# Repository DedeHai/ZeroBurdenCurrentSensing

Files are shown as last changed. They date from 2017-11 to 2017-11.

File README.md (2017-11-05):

# ZeroBurdenCurrentSensing
A circuit I made to measure the dynamically changing currents in low power microcontroller applications.

a detailed description is avialable on my blog: https://bashtelorofscience.wordpress.com/2017/11/05/zero-burden-voltage-current-amplifier/

Finished Circuit 
Example measurement

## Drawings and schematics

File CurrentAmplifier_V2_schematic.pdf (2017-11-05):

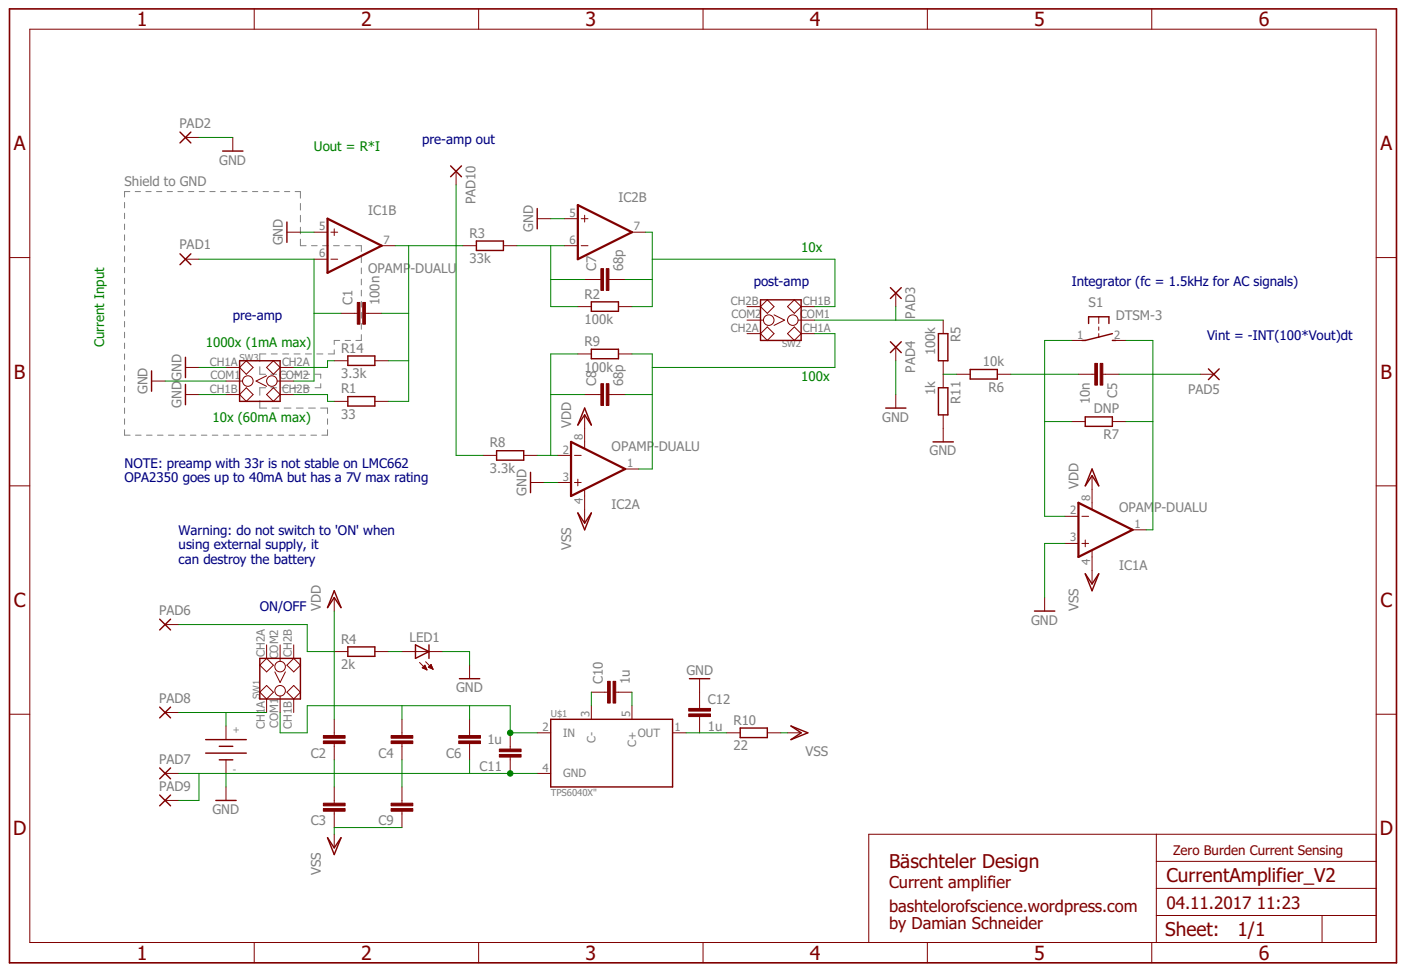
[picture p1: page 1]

pre-amp out Uout = R*I

Integrator (fc = 1.5kHz for AC signals)

Vint = -INT(100*Vout)dt

NOTE: preamp with 33r is not stable on LMC662
OPA2350 goes up to 40mA but has a 7V max rating

Warning: do not switch to 'ON' when
using external supply, it
can destroy the battery

Zero Burden Current Sensing Bäschteler Design

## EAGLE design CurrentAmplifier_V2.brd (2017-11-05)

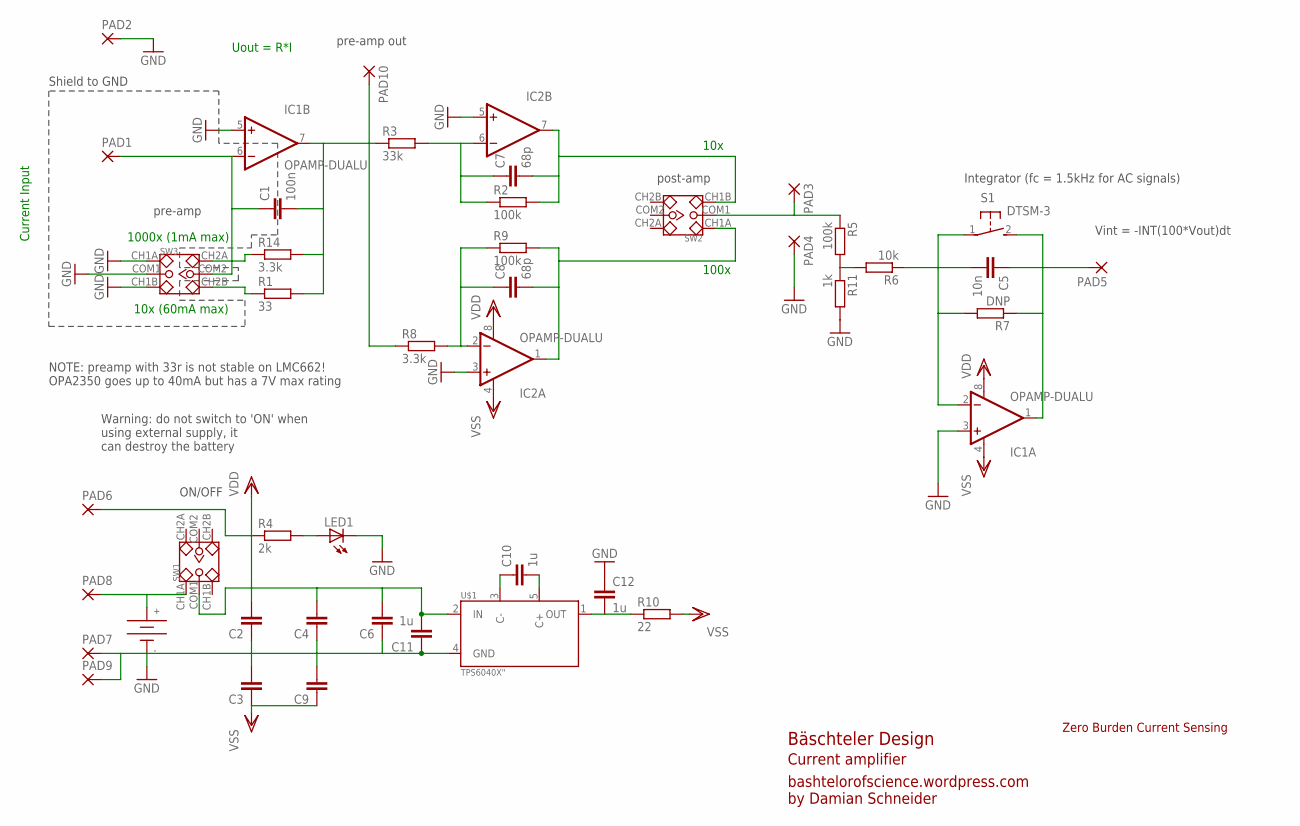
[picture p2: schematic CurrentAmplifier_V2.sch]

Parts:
C1: 100n; C0805K
C2, C3, C4: C-EUC0805; C0805
C5: 10n; C0805K
C6, C9: C-EUC1206; C1206
C7, C8: 68p; C0603
C10, C11, C12: 1u; C0603
CR1: DX_CR2032HANDSOLDER; DX_CR2032_SMD_HANDSOLDER
IC1, IC2: OPAMP-DUALU; SO08
LED1: LEDCHIP-LED0805; CHIP-LED0805
PAD1, PAD2, PAD3, PAD4, PAD5, PAD6, PAD7, PAD8, PAD9, PAD10: 1,6/0,9
R1: 33; R0805
R2, R5, R9: 100k; R0603
R3: 33k; R0603
R4: 2k; R0603
R6: 10k; R0603
R7: DNP; R0805
R8: 3.3k; R0603
R10: 22; R0805
R11: 1k; R0603
R14: 3.3k; R0805
S1: DTSM-3
SW1, SW2, SW3: DIP-TOGGLE-SWITCH-2CH-(2X3P-2.54); SW6-2.54-9.0X3.5X3.2+2.0MM
U$1: TPS6040X"; SOT23-5

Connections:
+: CR1.P$1 (+), PAD8.1, SW1.CH1A
GND: C2.1, C3.2, C4.1, C6.1, C9.2, C11.1, C12.1, CR1.P$2 (-), IC1.3 (+IN), IC1.5 (+IN), IC2.3 (+IN), IC2.5 (+IN), LED1.C, PAD2.1, PAD4.1, PAD7.1, PAD9.1, R11.2, SW3.CH1A, SW3.CH1B, SW3.COM1, U$1.4 (GND)
unnamed: C1.2, IC1.7 (OUT), PAD10.1, R1.2, R3.1, R8.1, R14.2
unnamed: C7.1, IC2.6 (-IN), R2.1, R3.2
unnamed: R5.2, R6.2, R11.1
unnamed: C7.2, IC2.7 (OUT), R2.2, SW2.CH1B
unnamed: R14.1, SW3.CH2A
unnamed: C10.1, U$1.3 (C-)
unnamed: C10.2, U$1.5 (C+)
unnamed: LED1.A, R4.2
unnamed: C5.2, IC1.2 (-IN), R6.1, R7.2, S1.1
unnamed: C5.1, IC1.1 (OUT), PAD5.1, R7.1, S1.2
unnamed: C8.1, IC2.2 (-IN), R8.2, R9.1
unnamed: C8.2, IC2.1 (OUT), R9.2, SW2.CH1A
unnamed: PAD3.1, R5.1, SW2.COM1
unnamed: C12.2, R10.1, U$1.1 (OUT)
unnamed: C1.1, IC1.6 (-IN), PAD1.1, SW3.COM2
unnamed: R1.1, SW3.CH2B
VDD: C2.2, C4.2, C6.2, C11.2, IC1.8 (V+), IC2.8 (V+), PAD6.1, R4.1, SW1.COM1, U$1.2 (IN)
VSS: C3.1, C9.1, IC1.4 (V-), IC2.4 (V-), R10.2

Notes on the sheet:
Uout = R*I
Current Input
Shield to GND
10x
100x
ON/OFF
post-amp
1000x (1mA max)
10x (60mA max)
pre-amp
Zero Burden Current Sensing
Integrator (fc = 1.5kHz for AC signals)
Warning: do not switch to 'ON' when using external supply, it can destroy the battery
Vint = -INT(100*Vout)dt
NOTE: preamp with 33r is not stable on LMC662! OPA2350 goes up to 40mA but has a 7V max rating
pre-amp out
Bäschteler Design
bashtelorofscience.wordpress.com by Damian Schneider
Current amplifier

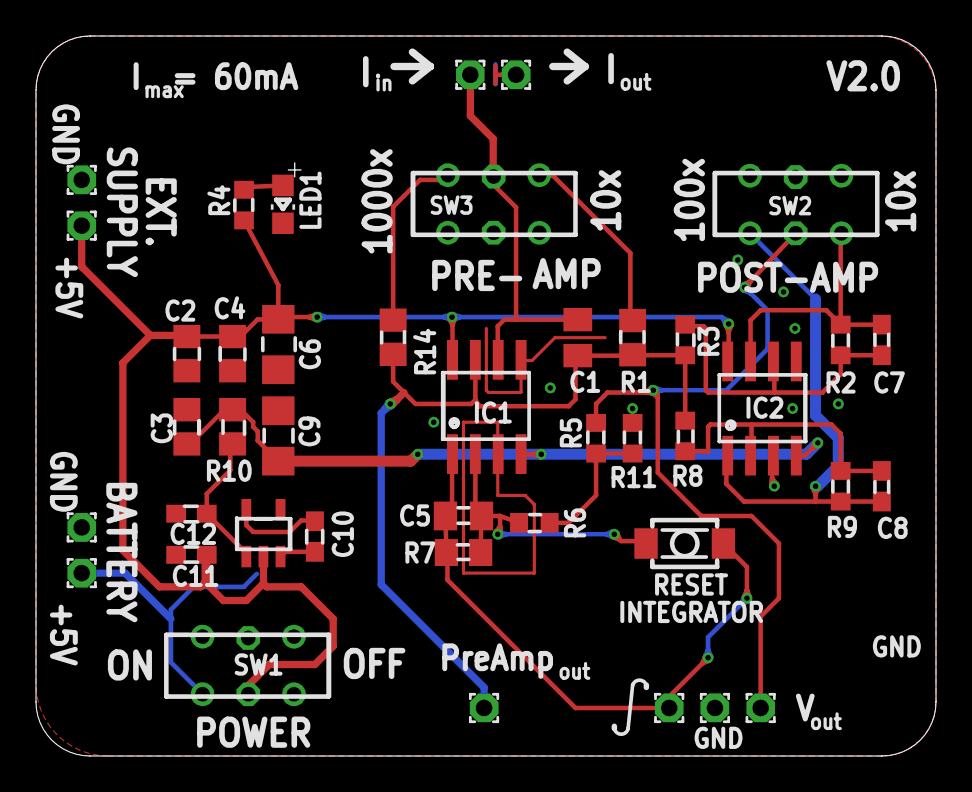
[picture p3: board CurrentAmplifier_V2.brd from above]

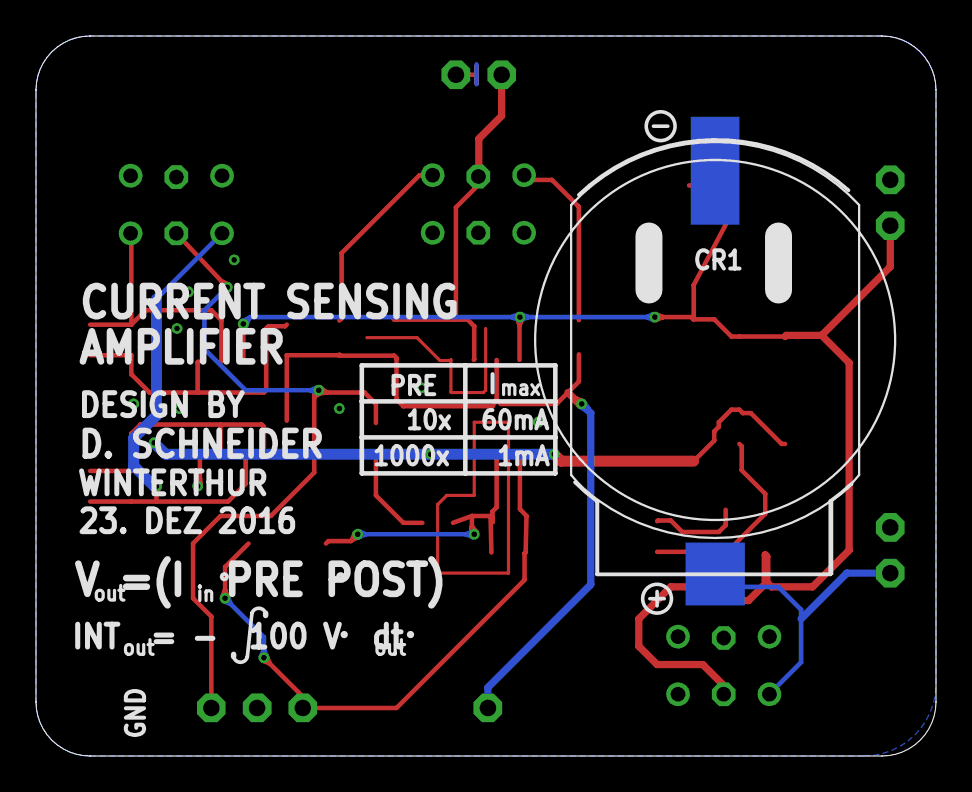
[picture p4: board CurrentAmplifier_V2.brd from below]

Board: 2 copper layers, 50.0 x 40.0 mm, 45 parts (3 on the bottom side), 20 nets.

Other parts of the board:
U$2: CC-BY-NC-SA_SR
U$5: OSH_LOGO_L_SR

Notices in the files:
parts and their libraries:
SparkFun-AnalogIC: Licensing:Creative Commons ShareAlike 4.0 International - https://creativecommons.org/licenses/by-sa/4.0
